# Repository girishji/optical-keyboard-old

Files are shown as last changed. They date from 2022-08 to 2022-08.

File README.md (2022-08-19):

# optical-keyboard

Keyboard PCB for Gateron optical switches (KiCad project).

- See [Optical Keyboard Design](https://girishji.github.io/jekyll/update/2022/08/17/optical-keyboard-design.html)
- There is a python script that is used for placing switches and laying out
  tracks. See also [KiCad 6 Python Scripting](https://girishji.github.io/)
- [QMK](https://github.com/girishji/qmk_firmware/tree/giri-optical-matrix/keyboards/opticalkb) code for this keyboard
- There is KiCad project for switch cutout plate under `switch-coutout` directory
- Part numbers for JLCPCB are embedded into symbols
- There is also a [single switch PCB](https://github.com/girishji/optical-amoeba)
- Another optical [keyboard](https://github.com/Dachtire/sok42) that might interest you
- Blackpill reference, including [pins to avoid](https://docs.qmk.fm/#/platformdev_blackpill_f411)

***





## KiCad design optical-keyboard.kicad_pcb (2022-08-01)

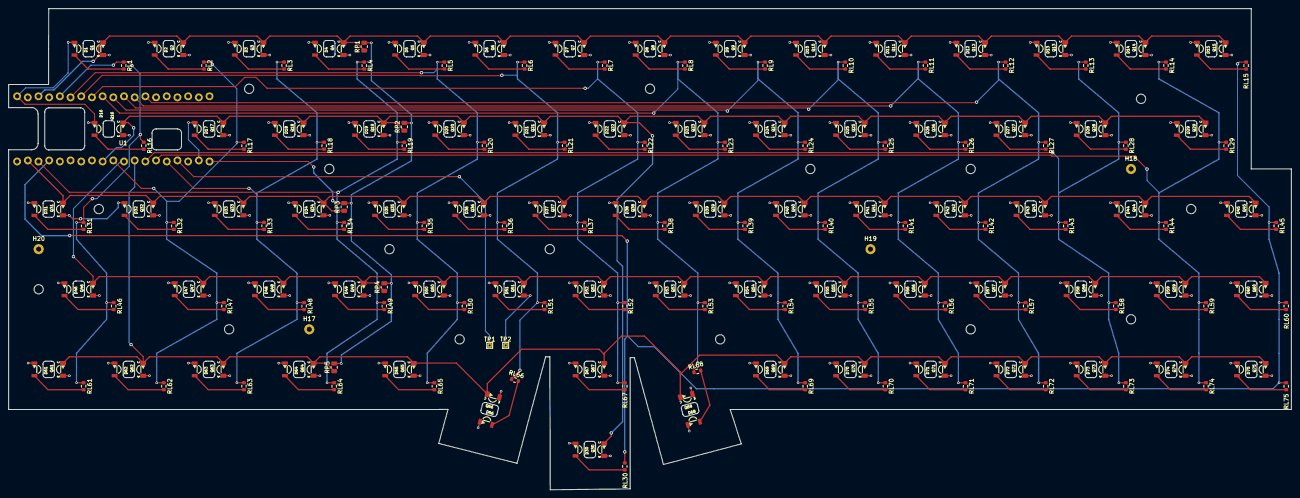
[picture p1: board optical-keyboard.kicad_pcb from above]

Board: 2 copper layers, 304.8 x 114.3 mm, 328 parts (0 on the bottom side), 98 nets.

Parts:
D1, D2, D3, D4, D5, D6, D7, D8, D9, D10, D11, D12, D13, D14, D15, D16, D17, D18, D19, D20, D21, D22, D23, D24, D25, D26, D27, D28, D29, D30, D31, D32, D33, D34, D35, D36, D37, D38, D39, D40, D41, D42, D43, D44, D45, D46, D47, D48, D49, D50, D51, D52, D53, D54, D55, D56, D57, D58, D59, D60, D61, D62, D63, D64, D65, D66, D67, D68, D69, D70, D71, D72, D73, D74, D75: IR_LED; Everlight_IR_IR12-21C_TR8
H1, H2, H3, H4, H5, H6, H7, H8, H9, H10, H11, H12, H13, H14, H15, H16: MountingHole; MountingHole_2.2mm_M2_jlcpcb
H17, H18, H19, H20: MountingHole; TestPoint_Plated_Hole_D1.2mm
Q1, Q2, Q3, Q4, Q5, Q6, Q7, Q8, Q9, Q10, Q11, Q12, Q13, Q14, Q15, Q16, Q17, Q18, Q19, Q20, Q21, Q22, Q23, Q24, Q25, Q26, Q27, Q28, Q29, Q30, Q31, Q32, Q33, Q34, Q35, Q36, Q37, Q38, Q39, Q40, Q41, Q42, Q43, Q44, Q45, Q46, Q47, Q48, Q49, Q50, Q51, Q52, Q53, Q54, Q55, Q56, Q57, Q58, Q59, Q60, Q61, Q62, Q63, Q64, Q65, Q66, Q67, Q68, Q69, Q70, Q71, Q72, Q73, Q74, Q75: Q_Photo_NPN; Everlight_PT_PT12-21C_TR8
RL1, RL2, RL3, RL4, RL5, RL6, RL7, RL8, RL9, RL10, RL11, RL12, RL13, RL14, RL15, RL16, RL17, RL18, RL19, RL20, RL21, RL22, RL23, RL24, RL25, RL26, RL27, RL28, RL29, RL30, RL31, RL32, RL33, RL34, RL35, RL36, RL37, RL38, RL39, RL40, RL41, RL42, RL43, RL44, RL45, RL46, RL47, RL48, RL49, RL50, RL51, RL52, RL53, RL54, RL55, RL56, RL57, RL58, RL59, RL60, RL61, RL62, RL63, RL64, RL65, RL66, RL67, RL68, RL69, RL70, RL71, RL72, RL73, RL74, RL75: R_Led; R_0603_1608Metric
RP1, RP2, RP3, RP4, RP5: R_PT; R_0805_2012Metric
S1, S2, S3, S4, S5, S6, S7, S8, S9, S10, S11, S12, S13, S14, S15, S16, S17, S18, S19, S20, S21, S22, S23, S24, S25, S26, S27, S28, S29, S30, S31, S32, S33, S34, S35, S36, S37, S38, S39, S40, S41, S42, S43, S44, S45, S46, S47, S48, S49, S50, S51, S52, S53, S54, S55, S56, S57, S58, S59, S60, S61, S62, S63, S64, S65, S66, S67, S68, S69, S70, S71, S72, S73, S74, S75: Gateron_Optical; Gateron_Switch_Basic
TP1, TP2: TestPoint; TestPoint_THTPad_1.0x1.0mm_Drill0.5mm
U1: BlackPill_STLINK; BlackPill_STLINK2

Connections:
3v3: RP1.2, RP2.2, RP3.2, RP4.2, RP5.2, U1.20 (3V3)
/Capslock_Led: TP1.1, U1.17 (PB9)
/col1: RL1.1, RL16.1, RL31.1, RL46.1, RL61.1, U1.35 (PB1)
/col2: RL2.1, RL17.1, RL32.1, RL47.1, RL62.1, U1.11 (PB3)
/col3: RL3.1, RL18.1, RL33.1, RL48.1, RL63.1, U1.16 (PB8)
/col4: RL4.1, RL19.1, RL34.1, RL49.1, RL64.1, U1.4 (PB15)
/col5: RL5.1, RL20.1, RL35.1, RL50.1, RL65.1, U1.34 (PB0)
/col6: RL6.1, RL21.1, RL36.1, RL51.1, RL66.1, U1.33 (PA7)
/col7: RL7.1, RL22.1, RL37.1, RL52.1, RL67.1, U1.32 (PA6)
/col8: RL8.1, RL23.1, RL38.1, RL53.1, RL68.1, U1.31 (PA5)
/col9: RL9.1, RL24.1, RL39.1, RL54.1, RL69.1, U1.30 (PA4)
/col10: RL10.1, RL25.1, RL40.1, RL55.1, RL70.1, U1.29 (PA3)
/col11: RL11.1, RL26.1, RL41.1, RL56.1, RL71.1, U1.28 (PA2)
/col12: RL12.1, RL27.1, RL42.1, RL57.1, RL72.1, U1.27 (PA1)
/col13: RL13.1, RL28.1, RL43.1, RL58.1, RL73.1, U1.14 (PB6)
/col14: RL14.1, RL29.1, RL44.1, RL59.1, RL74.1, U1.15 (PB7)
/col15: RL15.1, RL30.1, RL45.1, RL60.1, RL75.1, U1.5 (PA8)
/row1: Q1.1 (C), Q2.1 (C), Q3.1 (C), Q4.1 (C), Q5.1 (C), Q6.1 (C), Q7.1 (C), Q8.1 (C), Q9.1 (C), Q10.1 (C), Q11.1 (C), Q12.1 (C), Q13.1 (C), Q14.1 (C), Q15.1 (C), RP1.1, U1.37 (PB10)
/row2: Q16.1 (C), Q17.1 (C), Q18.1 (C), Q19.1 (C), Q20.1 (C), Q21.1 (C), Q22.1 (C), Q23.1 (C), Q24.1 (C), Q25.1 (C), Q26.1 (C), Q27.1 (C), Q28.1 (C), Q29.1 (C), Q30.1 (C), RP2.1, U1.10 (PA15)
/row3: Q31.1 (C), Q32.1 (C), Q33.1 (C), Q34.1 (C), Q35.1 (C), Q36.1 (C), Q37.1 (C), Q38.1 (C), Q39.1 (C), Q40.1 (C), Q41.1 (C), Q42.1 (C), Q43.1 (C), Q44.1 (C), Q45.1 (C), RP3.1, U1.3 (PB14)
/row4: Q46.1 (C), Q47.1 (C), Q48.1 (C), Q49.1 (C), Q50.1 (C), Q51.1 (C), Q52.1 (C), Q53.1 (C), Q54.1 (C), Q55.1 (C), Q56.1 (C), Q57.1 (C), Q58.1 (C), Q59.1 (C), Q60.1 (C), RP4.1, U1.12 (PB4)
/row5: Q61.1 (C), Q62.1 (C), Q63.1 (C), Q64.1 (C), Q65.1 (C), Q66.1 (C), Q67.1 (C), Q68.1 (C), Q69.1 (C), Q70.1 (C), Q71.1 (C), Q72.1 (C), Q73.1 (C), Q74.1 (C), Q75.1 (C), RP5.1, U1.13 (PB5)
GND: D1.1 (K), D2.1 (K), D3.1 (K), D4.1 (K), D5.1 (K), D6.1 (K), D7.1 (K), D8.1 (K), D9.1 (K), D10.1 (K), D11.1 (K), D12.1 (K), D13.1 (K), D14.1 (K), D15.1 (K), D16.1 (K), D17.1 (K), D18.1 (K), D19.1 (K), D20.1 (K), D21.1 (K), D22.1 (K), D23.1 (K), D24.1 (K), D25.1 (K), D26.1 (K), D27.1 (K), D28.1 (K), D29.1 (K), D30.1 (K), D31.1 (K), D32.1 (K), D33.1 (K), D34.1 (K), D35.1 (K), D36.1 (K), D37.1 (K), D38.1 (K), D39.1 (K), D40.1 (K), D41.1 (K), D42.1 (K), D43.1 (K), D44.1 (K), D45.1 (K), D46.1 (K), D47.1 (K), D48.1 (K), D49.1 (K), D50.1 (K), D51.1 (K), D52.1 (K), D53.1 (K), D54.1 (K), D55.1 (K), D56.1 (K), D57.1 (K), D58.1 (K), D59.1 (K), D60.1 (K), D61.1 (K), D62.1 (K), D63.1 (K), D64.1 (K), D65.1 (K), D66.1 (K), D67.1 (K), D68.1 (K), D69.1 (K), D70.1 (K), D71.1 (K), D72.1 (K), D73.1 (K), D74.1 (K), D75.1 (K), Q1.2 (E), Q2.2 (E), Q3.2 (E), Q4.2 (E), Q5.2 (E), Q6.2 (E), Q7.2 (E), Q8.2 (E), Q9.2 (E), Q10.2 (E), Q11.2 (E), Q12.2 (E), Q13.2 (E), Q14.2 (E), Q15.2 (E), Q16.2 (E), Q17.2 (E), Q18.2 (E), Q19.2 (E), Q20.2 (E), Q21.2 (E), Q22.2 (E), Q23.2 (E), Q24.2 (E), Q25.2 (E), Q26.2 (E), Q27.2 (E), Q28.2 (E), Q29.2 (E), Q30.2 (E), Q31.2 (E), Q32.2 (E), Q33.2 (E), Q34.2 (E), Q35.2 (E), Q36.2 (E), Q37.2 (E), Q38.2 (E), Q39.2 (E), Q40.2 (E), Q41.2 (E), Q42.2 (E), Q43.2 (E), Q44.2 (E), Q45.2 (E), Q46.2 (E), Q47.2 (E), Q48.2 (E), Q49.2 (E), Q50.2 (E), Q51.2 (E), Q52.2 (E), Q53.2 (E), Q54.2 (E), Q55.2 (E), Q56.2 (E), Q57.2 (E), Q58.2 (E), Q59.2 (E), Q60.2 (E), Q61.2 (E), Q62.2 (E), Q63.2 (E), Q64.2 (E), Q65.2 (E), Q66.2 (E), Q67.2 (E), Q68.2 (E), Q69.2 (E), Q70.2 (E), Q71.2 (E), Q72.2 (E), Q73.2 (E), Q74.2 (E), Q75.2 (E), TP2.1, U1.19 (GND), U1.39 (GND)
unnamed: D1.2 (A), RL1.2
unnamed: D2.2 (A), RL2.2
unnamed: D3.2 (A), RL3.2
unnamed: D4.2 (A), RL4.2
unnamed: D5.2 (A), RL5.2
unnamed: D6.2 (A), RL6.2
unnamed: D7.2 (A), RL7.2
unnamed: D8.2 (A), RL8.2
unnamed: D9.2 (A), RL9.2
unnamed: D10.2 (A), RL10.2
unnamed: D11.2 (A), RL11.2
unnamed: D12.2 (A), RL12.2
unnamed: D13.2 (A), RL13.2
unnamed: D14.2 (A), RL14.2
unnamed: D15.2 (A), RL15.2
unnamed: D16.2 (A), RL16.2
unnamed: D17.2 (A), RL17.2
unnamed: D18.2 (A), RL18.2
unnamed: D19.2 (A), RL19.2
unnamed: D20.2 (A), RL20.2
unnamed: D21.2 (A), RL21.2
unnamed: D22.2 (A), RL22.2
unnamed: D23.2 (A), RL23.2
unnamed: D24.2 (A), RL24.2
unnamed: D25.2 (A), RL25.2
unnamed: D26.2 (A), RL26.2
unnamed: D27.2 (A), RL27.2
unnamed: D28.2 (A), RL28.2
unnamed: D29.2 (A), RL29.2
unnamed: D30.2 (A), RL30.2
unnamed: D31.2 (A), RL31.2
unnamed: D32.2 (A), RL32.2
unnamed: D33.2 (A), RL33.2
unnamed: D34.2 (A), RL34.2
unnamed: D35.2 (A), RL35.2
unnamed: D36.2 (A), RL36.2
unnamed: D37.2 (A), RL37.2
unnamed: D38.2 (A), RL38.2
unnamed: D39.2 (A), RL39.2
unnamed: D40.2 (A), RL40.2
unnamed: D41.2 (A), RL41.2
unnamed: D42.2 (A), RL42.2
unnamed: D43.2 (A), RL43.2
unnamed: D44.2 (A), RL44.2
unnamed: D45.2 (A), RL45.2
unnamed: D46.2 (A), RL46.2
unnamed: D47.2 (A), RL47.2
unnamed: D48.2 (A), RL48.2
unnamed: D49.2 (A), RL49.2
unnamed: D50.2 (A), RL50.2
unnamed: D51.2 (A), RL51.2
unnamed: D52.2 (A), RL52.2
unnamed: D53.2 (A), RL53.2
unnamed: D54.2 (A), RL54.2
unnamed: D55.2 (A), RL55.2
unnamed: D56.2 (A), RL56.2
unnamed: D57.2 (A), RL57.2
unnamed: D58.2 (A), RL58.2
unnamed: D59.2 (A), RL59.2
unnamed: D60.2 (A), RL60.2
unnamed: D61.2 (A), RL61.2
unnamed: D62.2 (A), RL62.2
unnamed: D63.2 (A), RL63.2
unnamed: D64.2 (A), RL64.2
unnamed: D65.2 (A), RL65.2
unnamed: D66.2 (A), RL66.2
unnamed: D67.2 (A), RL67.2
unnamed: D68.2 (A), RL68.2
unnamed: D69.2 (A), RL69.2
unnamed: D70.2 (A), RL70.2
unnamed: D71.2 (A), RL71.2
unnamed: D72.2 (A), RL72.2
unnamed: D73.2 (A), RL73.2
unnamed: D74.2 (A), RL74.2
unnamed: D75.2 (A), RL75.2

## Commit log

2022-07-19 first commit
    A .gitignore
    A fp-lib-table
    A optical-keyboard.kicad_pcb
    A optical-keyboard.kicad_prl
    A optical-keyboard.kicad_pro
    A optical-keyboard.kicad_sch
    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
    [optical-keyboard.kicad_pcb, optical-keyboard.kicad_sch, switch-cutout.kicad_pcb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]
2022-07-20 updated pcb
    M optical-keyboard.kicad_pcb
    M optical-keyboard.kicad_pro
    M optical-keyboard.kicad_sch
    M placefp.py
    M switch.kicad_sch
    [optical-keyboard.kicad_pcb, optical-keyboard.kicad_sch, switch.kicad_sch]
2022-07-20 update schematic
    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
    [optical-keyboard.kicad_sch, switch.kicad_sch]
2022-07-21 update footprint
    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
    [optical-keyboard.kicad_pcb]
2022-07-30 Added description
    M README.md
    M switch-cutout/switch-cutout.kicad_pro
    A switch-cutout/sym-lib-table
    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
2022-07-31 Fixed bug in symbols by removing arrows
    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
    [optical-keyboard.kicad_sch, switch.kicad_sch]
2022-08-01 Add separate power source for PTs
    Sharing input pin b/w pt and led requires a diode, and diode
    slows down the response time of pt considerably
    M optical-keyboard.kicad_prl
    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
    [optical-keyboard.kicad_pcb, optical-keyboard.kicad_sch, switch.kicad_sch]
2022-08-01 Add footprints library
    A OpticalSymbols_Library.kicad_sym
    A Optical_Parts.pretty/BlackPill_STLINK.kicad_mod
    A Optical_Parts.pretty/BlackPill_STLINK2.kicad_mod
    A Optical_Parts.pretty/Everlight_IR_IR12-21C_TR8.kicad_mod
    A Optical_Parts.pretty/Everlight_PT_PT12-21C_TR8.kicad_mod
    A Optical_Parts.pretty/Gateron_Optical_Switch.kicad_mod
    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
    [optical-keyboard.kicad_pcb, switch.kicad_sch]
2022-08-03 Fix footprint hole size
    Cutouts should be 14x14 mm, not 13.8mm square; This fits
    both gateron and keychron optical switches
    M Optical_Parts.pretty/Switch_Cutout.kicad_mod
    M Optical_Parts.pretty/Switch_Cutout_1.25u.kicad_mod
    M Optical_Parts.pretty/Switch_Cutout_1.5u.kicad_mod
    M Optical_Parts.pretty/Switch_Cutout_1.75u.kicad_mod
    M switch-cutout/fp-lib-table
    M switch-cutout/switch-cutout.kicad_pcb
    M switch-cutout/sym-lib-table
    [switch-cutout.kicad_pcb]
2022-08-19 update readme
    M switch-cutout/switch-cutout.kicad_prl
    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
